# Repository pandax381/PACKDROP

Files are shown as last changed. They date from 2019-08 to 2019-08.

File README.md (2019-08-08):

# PACKDROP

Raspberry Pi based Handmade Network Emulator (Packet loss and delay injector)

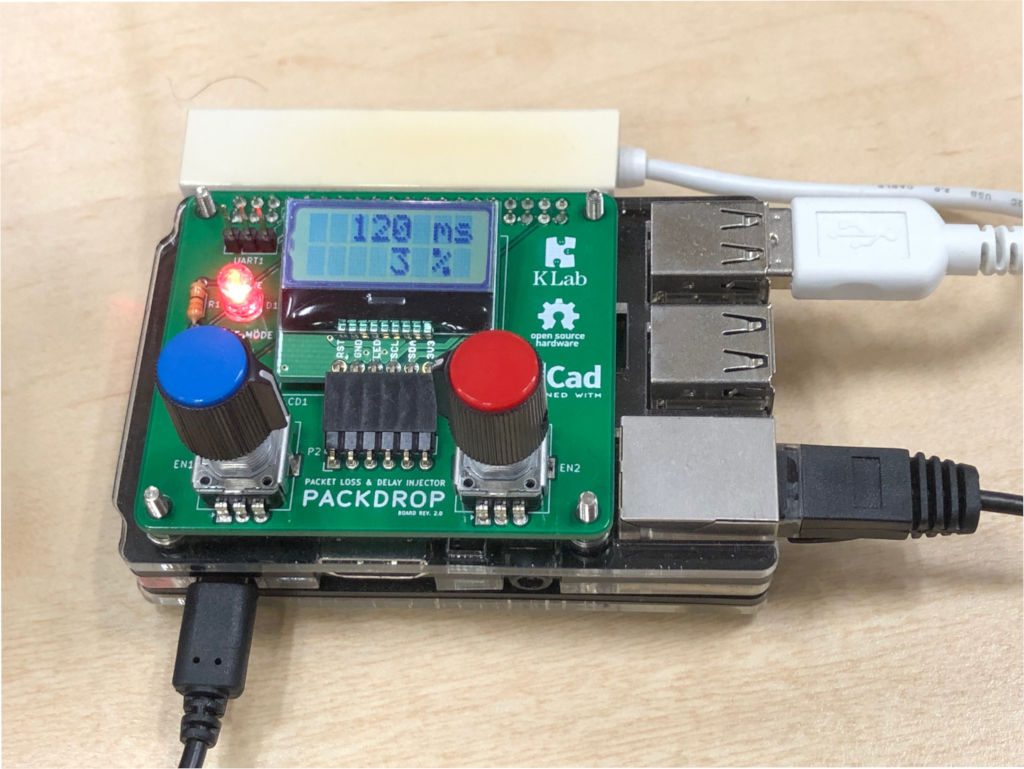
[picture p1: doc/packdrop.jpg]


## SD Image

### for BOARD REV. 2.0

+ [PACKDROP_2.0a.img](https://drive.google.com/file/d/1GBg2wHwh6UmLzyU2K1rythLRL9IAEKmV/view?usp=sharing) (Google Drive)

```
$ dd if=PACKDROP_2.0a.img of=/dev/sda bs=1m
```

*This image can be used with both Raspberry Pi 2B or 3B/3B+ (or 4B).*

### for BOARD REV. 1.2 or older

+ [PACKDROP_1.2.1.img](https://drive.google.com/file/d/0ByIrBGkSig1Pb3QyajJXTXBhd1U/view?usp=sharing) (Google Drive)

```
$ dd if=PACKDROP_1.2.1.img of=/dev/sda bs=1m
```

*This image can be used with both Raspberry Pi 2B or 3B.*

## Configuration

The following files are copied from sdcard to rootfs at boot time.

- interfaces.txt -> /etc/network/interfaces
- hostapd.txt -> /etc/hostapd/hostapd.conf

The target interface is a member of br0.<br/>
By setting these files, you can also use the vlan interface.

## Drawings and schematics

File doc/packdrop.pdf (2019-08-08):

## PACKDROP - Handmade Network Emulator

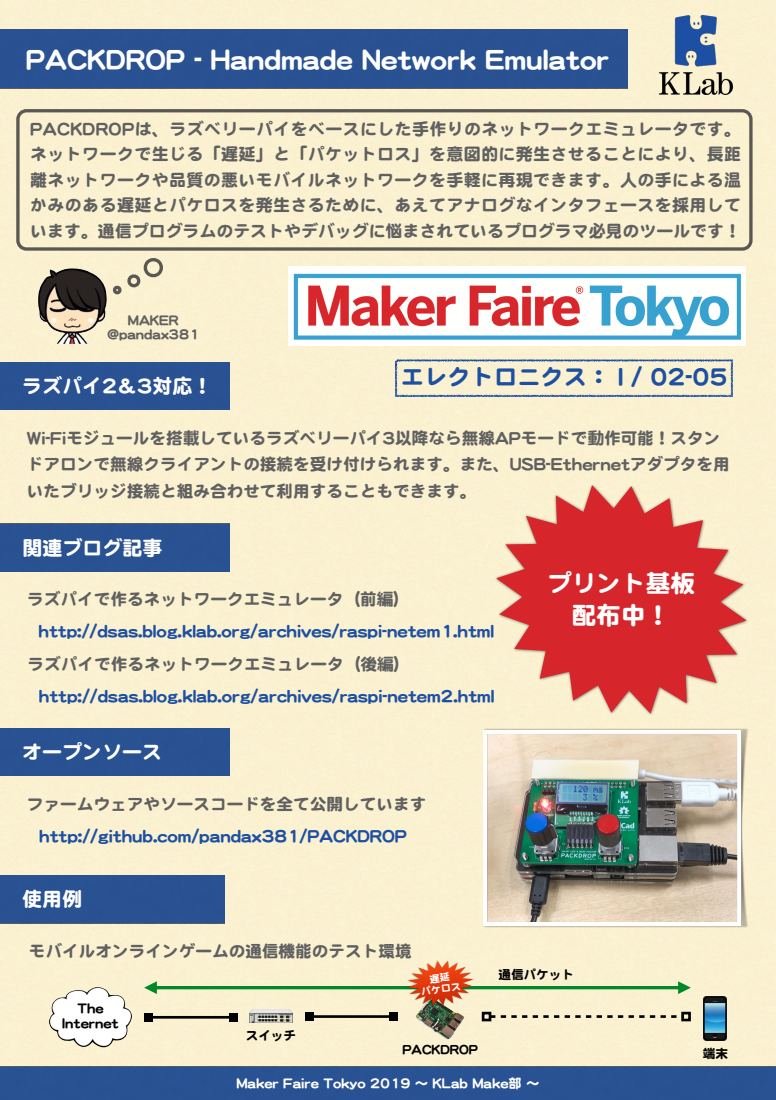
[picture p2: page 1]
使用例; スイッチ; PACKDROP; 遅延 パケロス; 通信パケット; The Internet; モバイルオンラインゲームの通信機能のテスト環境; MAKER @pandax381; エレクトロニクス： I / 02-05; ファームウェアやソースコードを全て公開しています; オープンソース; ラズパイで作るネットワークエミュレータ（前編）; 関連ブログ記事; ラズパイで作るネットワークエミュレータ（後編）; ラズパイ2＆3対応！; プリント基板 配布中！

PACKDROPは、ラズベリーパイをベースにした手作りのネットワークエミュレータです。
ネットワークで生じる「遅延」と「パケットロス」を意図的に発生させることにより、長距
離ネットワークや品質の悪いモバイルネットワークを手軽に再現できます。人の手による温
かみのある遅延とパケロスを発生さるために、あえてアナログなインタフェースを採用して
います。通信プログラムのテストやデバッグに悩まされているプログラマ必見のツールです！

Wi-Fiモジュールを搭載しているラズベリーパイ3以降なら無線APモードで動作可能！スタン
ドアロンで無線クライアントの接続を受け付けられます。また、USB-Ethernetアダプタを用
いたブリッジ接続と組み合わせて利用することもできます。

http://dsas.blog.klab.org/archives/raspi-netem1.html

http://dsas.blog.klab.org/archives/raspi-netem2.html

http://github.com/pandax381/PACKDROP

Maker Faire Tokyo 2019 〜 KLab Make部 〜

## PACKDROP 組み立てガイド

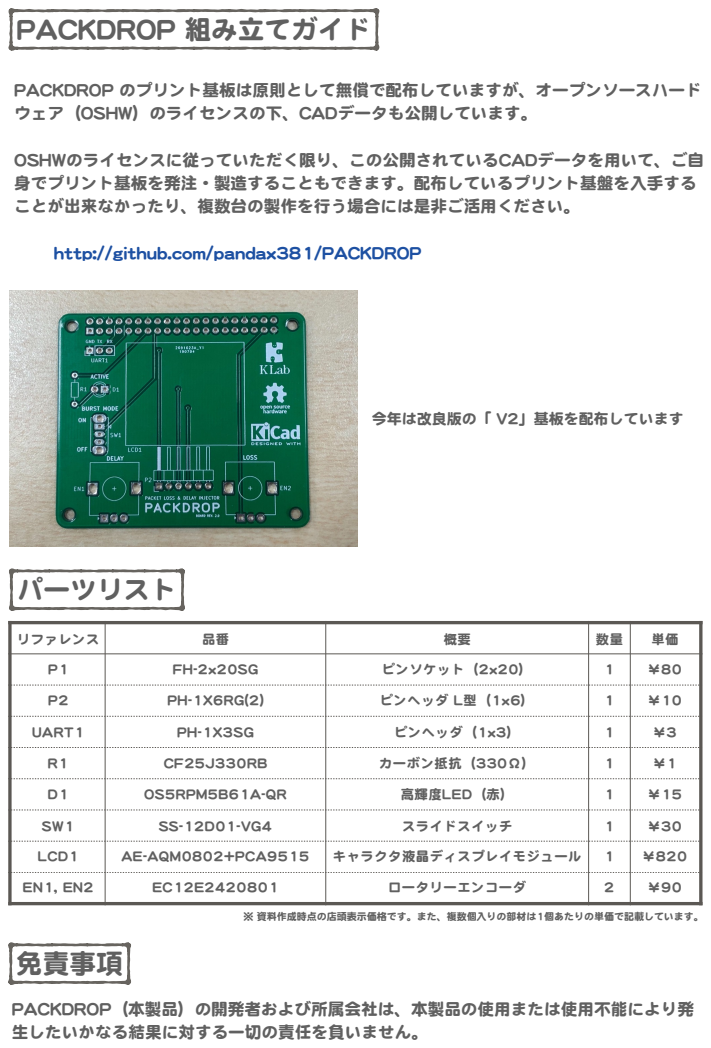
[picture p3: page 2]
リファレンス; ピンソケット（2x20）; ピンヘッダ L型（1x6）; UART1; ピンヘッダ（1x3）; カーボン抵抗（330Ω）; OS5RPM5B61A-QR; 高輝度LED（赤）; スライドスイッチ; LCD1; AE-AQM0802+PCA9515; キャラクタ液晶ディスプレイモジュール; ロータリーエンコーダ; パーツリスト; ※ 資料作成時点の店頭表示価格です。また、複数個入りの部材は1個あたりの単価で記載しています。; 免責事項; 今年は改良版の「 V2」基板を配布しています

PACKDROP のプリント基板は原則として無償で配布していますが、オープンソースハード
ウェア（OSHW）のライセンスの下、CADデータも公開しています。

OSHWのライセンスに従っていただく限り、この公開されているCADデータを用いて、ご自
身でプリント基板を発注・製造することもできます。配布しているプリント基盤を入手する
ことが出来なかったり、複数台の製作を行う場合には是非ご活用ください。

http://github.com/pandax381/PACKDROP

PACKDROP（本製品）の開発者および所属会社は、本製品の使用または使用不能により発
生したいかなる結果に対する一切の責任を負いません。

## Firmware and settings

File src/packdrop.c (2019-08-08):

#include <stdio.h>
#include <stdio.h>
#include <stdlib.h>
#include <string.h>
#include <unistd.h>
#include <math.h>
#include <wiringPi.h>
#include <wiringPiSPI.h>

#define APP_NAME     "PACKDROP"
#define APP_VERSION  "v2.0a"

#define PIN_LED (27)
#define PIN_SW  (22)
#define PIN_D_A (5)
#define PIN_D_B (6)
#define PIN_L_A (26)
#define PIN_L_B (16)

#define SW_ON   (0)

struct {
    int a;
    int b;
    struct {
        int a;
        int b;
    } p;
    int num;
    int min;
    int max;
} d = {1, 1, {0, 0}, 0, 0, 10000}, l = {1, 1, {0, 0}, 0, 0, 100};

struct {
    int num;
} s = {!SW_ON};

char **devices;
int devnum;

static void
tc_set (const char *dev, int delay, int loss) {
    char cmd[128];

    snprintf(cmd, sizeof(cmd), "tc qdisc change dev %s root netem limit 10000 delay %dms loss %d%%", dev, delay, loss);
    system(cmd);
}

static void
tc_init (const char *dev) {
    char cmd[128];

    snprintf(cmd, sizeof(cmd), "tc qdisc del dev %s root >/dev/null 2>&1", dev);
    system(cmd);
    snprintf(cmd, sizeof(cmd), "tc qdisc add dev %s root netem limit 10000 delay 0ms loss 0%%", dev);
    system(cmd);
}

static void
lcd_write_core (const char *upper, const char *lower) {
    char cmd[128];

    system("i2cset -y 1 0x3e 0 0x80 b");
    snprintf(cmd, sizeof(cmd), "i2cset -y 1 0x3e 0x40 0x%02x 0x%02x 0x%02x 0x%02x 0x%02x 0x%02x 0x%02x 0x%02x i",
        upper[0], upper[1], upper[2], upper[3], upper[4], upper[5], upper[6], upper[7]);
    system(cmd);

    system("i2cset -y 1 0x3e 0 0xc0 b");
    snprintf(cmd, sizeof(cmd), "i2cset -y 1 0x3e 0x40 0x%02x 0x%02x 0x%02x 0x%02x 0x%02x 0x%02x 0x%02x 0x%02x i",
        lower[0], lower[1], lower[2], lower[3], lower[4], lower[5], lower[6], lower[7]);
    system(cmd);
}

static void
lcd_write (int delay, int loss) {
    char upper[9], lower[9];

    snprintf(upper, sizeof(upper), "%5d ms", delay);
    snprintf(lower, sizeof(lower), "  %3d %% ", loss);
    lcd_write_core(upper, lower);
}

static void
lcd_init (void) {
    char name[9], ver[9];

    system("i2cset -y 1 0x3e 0 0x38 0x39 0x14 0x78 0x5f 0x6a i");
    system("i2cset -y 1 0x3e 0 0x0c 0x01 i");
    system("i2cset -y 1 0x3e 0 0x06 i");
    snprintf(name, sizeof(name), "%8s", APP_NAME);
    snprintf(ver, sizeof(ver), "%8s", APP_VERSION);
    lcd_write_core(name, ver);
}

static void
delay_inc (void) {
    int v;

    if (s.num == SW_ON) {
        return;
    }
    v = digitalRead(PIN_D_B);
    if (v != d.b) {
        d.p.b = d.b; d.b = v;
        if (!d.a && !d.b && d.p.a && d.p.b) {
            if (d.num < d.max) {
                d.num += d.num < 100 ? 1 : (d.num < 1000 ? 10 : 100);
            }
        }
    }
}

static void
delay_dec (void) {
    int v;

    if (s.num == SW_ON) {
        return;
    }
    v = digitalRead(PIN_D_A);
    if (v != d.a) {
        d.p.a = d.a; d.a = v;
        if (!d.a && !d.b && d.p.a && d.p.b) {
            if (d.num > d.min) {
                d.num -= d.num <= 100 ? 1 : (d.num <= 1000 ? 10 : 100);
            }
        }
    }
}

static void
loss_inc (void) {
    int v;

    if (s.num == SW_ON) {
        return;
    }
    v = digitalRead(PIN_L_B);
    if (v != l.b) {
        l.p.b = l.b; l.b = v;
        if (!l.a && !l.b && l.p.a && l.p.b) {
            if (l.num < l.max) {
                l.num += 1;
            }
        }
    }
}

void
loss_dec (void) {
    int v;

    if (s.num == SW_ON) {
        return;
    }
    v = digitalRead(PIN_L_A);
    if (v != l.a) {
        l.p.a = l.a; l.a = v;
        if (!l.a && !l.b && l.p.a && l.p.b) {
            if (l.num > l.min) {
                l.num -= 1;
            }
        }
    }
}

static void
sw_event (void) {
    s.num = digitalRead(PIN_SW);
}

static void
burst_mode (void) {
    int n;

    for (n = 0; n < devnum; n++) {
        tc_set(devices[n], 0, 100);
    }
    lcd_write_core(" burst  ", "   mode ");
    digitalWrite(PIN_LED, 1);
    while (1) {
        if (s.num != SW_ON) {
            break;
        }
        usleep(10000);
    }
}

int
main (int argc, char *argv[]) {
    int n, delay = 0, loss = 0;

    lcd_init();
    if (wiringPiSetupGpio() == -1) {
        fprintf(stderr, "wiringPiSetup: error\n");
        return -1;
    }
    /* LED */
    pinMode(PIN_LED, OUTPUT);
    digitalWrite(PIN_LED, 0);
    /* SW */
    pinMode(PIN_SW, INPUT);
    pullUpDnControl(PIN_SW, PUD_UP);
    wiringPiISR(PIN_SW, INT_EDGE_BOTH, sw_event);
    /* ENC (DELAY) */
    pinMode(PIN_D_A, INPUT);
    pinMode(PIN_D_B, INPUT);
    pullUpDnControl(PIN_D_A, PUD_UP);
    pullUpDnControl(PIN_D_B, PUD_UP);
    wiringPiISR(PIN_D_A, INT_EDGE_BOTH, delay_dec);
    wiringPiISR(PIN_D_B, INT_EDGE_BOTH, delay_inc);
    /* ENC (LOSS) */
    pinMode(PIN_L_A, INPUT);
    pinMode(PIN_L_B, INPUT);
    pullUpDnControl(PIN_L_A, PUD_UP);
    pullUpDnControl(PIN_L_B, PUD_UP);
    wiringPiISR(PIN_L_A, INT_EDGE_BOTH, loss_dec);
    wiringPiISR(PIN_L_B, INT_EDGE_BOTH, loss_inc);
    devices = argv + 1;
    devnum  = argc - 1;
    for (n = 0; n < devnum; n++) {
        tc_init(devices[n]);
    }
    while (1){
	if (s.num == SW_ON) {
            burst_mode();
            delay = loss = -1;
        }
        if (delay != d.num || loss != l.num) {
            delay = d.num;
            loss = l.num;
            for (n = 0; n < devnum; n++) {
                tc_set(devices[n], delay, loss);
            }
            lcd_write(delay, loss);
	    digitalWrite(PIN_LED, (delay || loss) ? 1 : 0);
        }
        usleep(10000);
    }
    return 0;
}

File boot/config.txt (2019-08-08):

# For more options and information see
# http://rpf.io/configtxt
# Some settings may impact device functionality. See link above for details

# uncomment if you get no picture on HDMI for a default "safe" mode
#hdmi_safe=1

# uncomment this if your display has a black border of unused pixels visible
# and your display can output without overscan
#disable_overscan=1

# uncomment the following to adjust overscan. Use positive numbers if console
# goes off screen, and negative if there is too much border
#overscan_left=16
#overscan_right=16
#overscan_top=16
#overscan_bottom=16

# uncomment to force a console size. By default it will be display's size minus
# overscan.
#framebuffer_width=1280
#framebuffer_height=720

# uncomment if hdmi display is not detected and composite is being output
#hdmi_force_hotplug=1

# uncomment to force a specific HDMI mode (this will force VGA)
#hdmi_group=1
#hdmi_mode=1

# uncomment to force a HDMI mode rather than DVI. This can make audio work in
# DMT (computer monitor) modes
#hdmi_drive=2

# uncomment to increase signal to HDMI, if you have interference, blanking, or
# no display
#config_hdmi_boost=4

# uncomment for composite PAL
#sdtv_mode=2

#uncomment to overclock the arm. 700 MHz is the default.
#arm_freq=800

# Uncomment some or all of these to enable the optional hardware interfaces
dtparam=i2c_arm=on
#dtparam=i2s=on
#dtparam=spi=on

# Uncomment this to enable the lirc-rpi module
#dtoverlay=lirc-rpi

# Additional overlays and parameters are documented /boot/overlays/README

# Enable audio (loads snd_bcm2835)
dtparam=audio=on

[pi4]
# Enable DRM VC4 V3D driver on top of the dispmanx display stack
dtoverlay=vc4-fkms-v3d
max_framebuffers=2

[all]
#dtoverlay=vc4-fkms-v3d

dtoverlay=pi3-miniuart-bt
core_freq=250

initramfs initramfs.img

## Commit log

2017-08-01 Add boot files
    [config.txt]
2017-08-07 Add gerber data
    [packdrop.gbl, packdrop.gbo, packdrop.gbs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]
2019-08-08 Add garber data for V2 board
    [PACKDROPv2.GBL, PACKDROPv2.GBO, PACKDROPv2.GBS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]
2019-08-08 Update boot files
    [config.txt]
